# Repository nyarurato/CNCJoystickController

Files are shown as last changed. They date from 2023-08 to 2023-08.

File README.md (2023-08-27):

# CNCJoystickController
CNC Joystick Controller for RepRap Firmware Duet3

Using in 
https://bbs.avalontech.jp/t/topic/1473

# DEMO

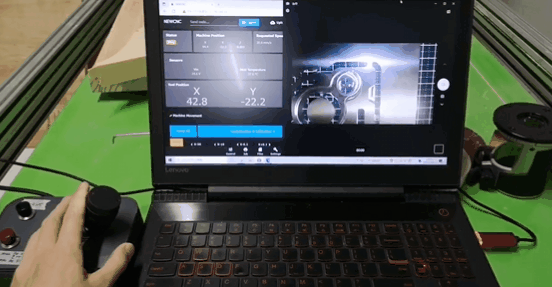
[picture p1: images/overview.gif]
demo


from: https://twitter.com/Gymnopedian/status/1694639996589015279

# Licence
## Hardware
[CC BY-SA 4.0](https://creativecommons.org/licenses/by-sa/4.0/)

## Software
[GPLv3](https://www.gnu.org/licenses/gpl-3.0.html)

Software is forked from https://github.com/Duet3D/CNC-Pendant-Firmware

# Author
[nyaruarto](https://github.com/nyarurato)

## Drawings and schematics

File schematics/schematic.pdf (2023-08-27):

# GND 2 5

JP1123

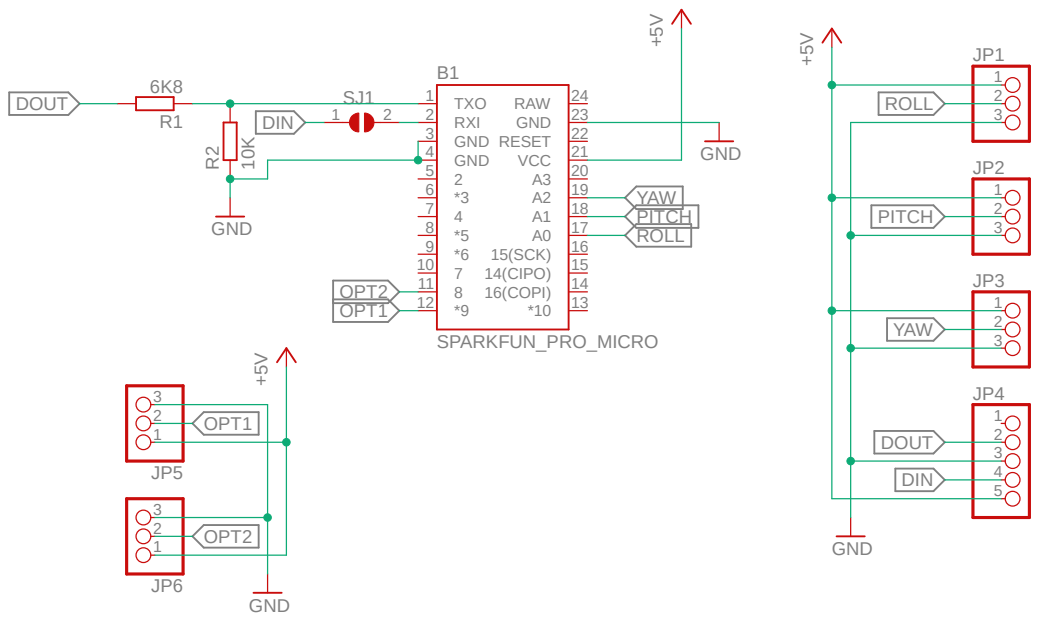
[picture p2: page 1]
SPARKFUN_PRO_MICRO ⁺⁵V; GND; GND +5V; 13 16(COPI); 14 14(CIPO); 15 15(SCK); 20 GND 4; 23 RAW; GND 3; RESET; 22 RXI 2; TXO 1; VCC; ROLL; PITCH; YAW; DOUT; DIN; OPT1; OPT2

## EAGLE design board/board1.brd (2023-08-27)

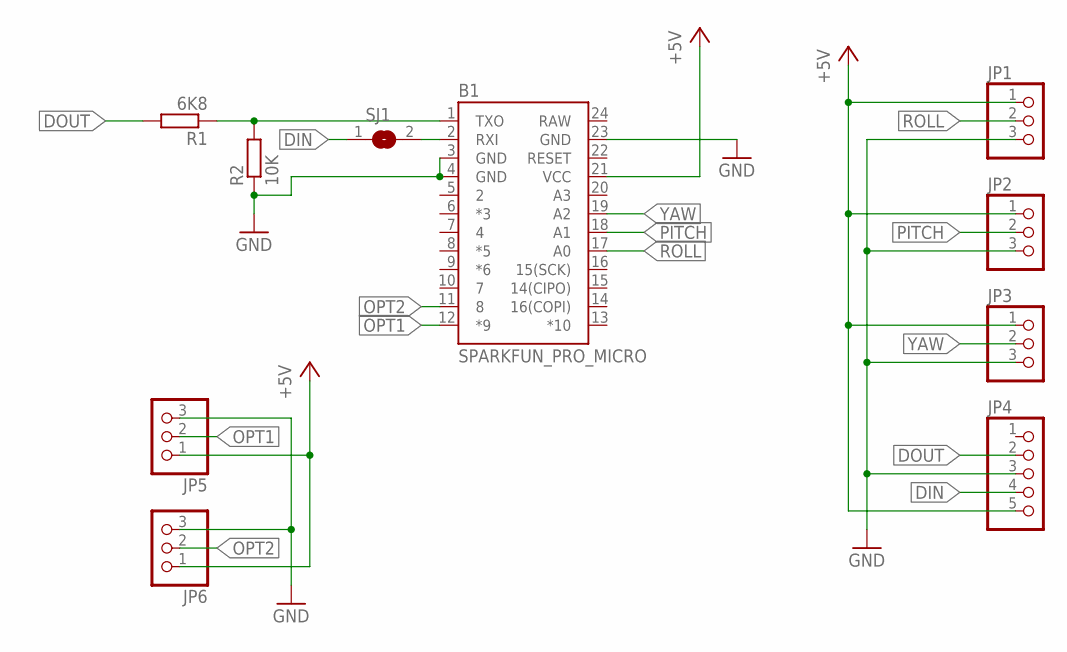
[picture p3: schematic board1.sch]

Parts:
B1: SPARKFUN_PRO_MICRO
JP1, JP2, JP3, JP5, JP6: PINHD-1X3; 1X03
JP4: PINHD-1X5; 1X05
R1: 6K8; R0603
R2: 10K; R0603
SJ1: SJ

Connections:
+5V: B1.21 (VCC), JP1.1, JP2.1, JP3.1, JP4.5, JP5.1, JP6.1
DIN: JP4.4, SJ1.1
DOUT: JP4.2, R1.2
GND: B1.3 (GND), B1.4 (GND), B1.23 (GND), JP1.3, JP2.3, JP3.3, JP4.3, JP5.3, JP6.3, R2.1
unnamed: B1.1 (TXO), R1.1, R2.2
unnamed: B1.2 (RXI), SJ1.2
OPT1: B1.12 (*9), JP5.2
OPT2: B1.11 (8), JP6.2
PITCH: B1.18 (A1), JP2.2
RAW: B1.24 (RAW)
ROLL: B1.17 (A0), JP1.2
YAW: B1.19 (A2), JP3.2

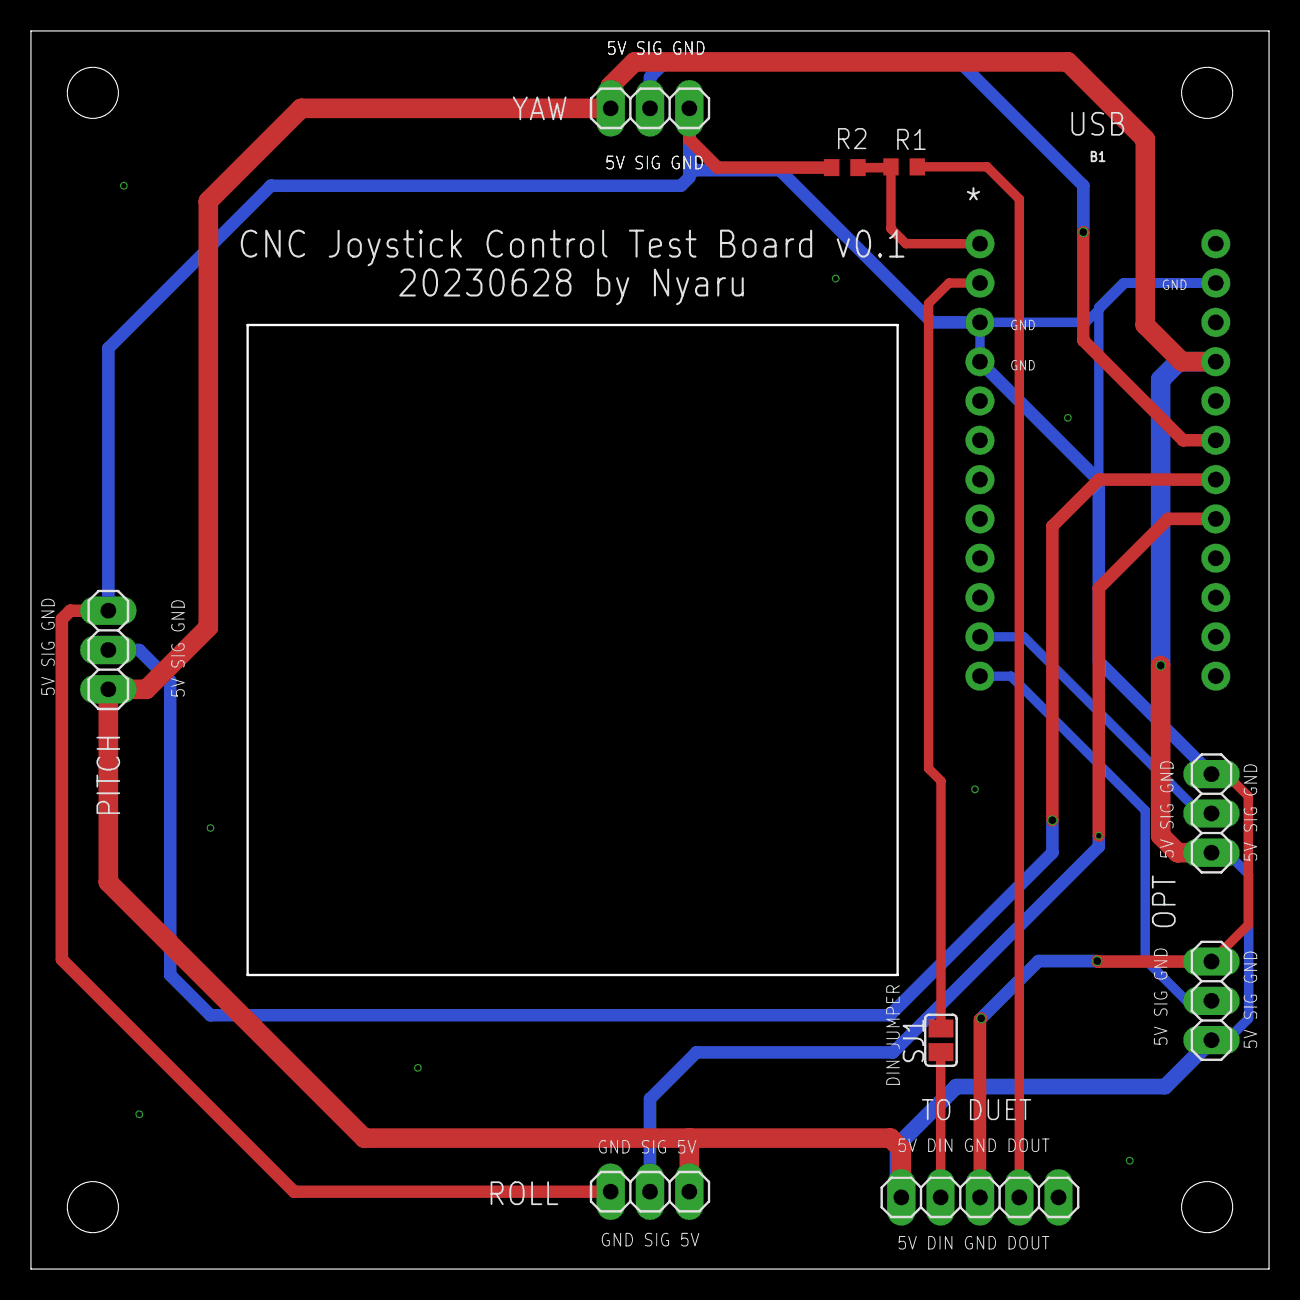
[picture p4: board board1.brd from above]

Board: 2 copper layers, 80.0 x 80.0 mm, 10 parts (0 on the bottom side), 11 nets.

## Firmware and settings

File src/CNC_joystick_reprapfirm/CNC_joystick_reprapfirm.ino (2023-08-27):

// CNC pendant interface to Duet
// Configuration constants
const int PinP = A1;
const int PinR = A0;
const int PinY = A2;

const int PinOP1 = 9;
const int PinOP2 = 8;

const unsigned long BaudRate = 57600;
const unsigned long MinCommandInterval = 20;

// Table of commands we send, one entry for each axis
const char* MoveCommands = "G91 G0 ";

#include "GCodeSerial.h"
#include "PassThrough.h"
PassThrough passThrough;

#include <avdweb_Switch.h>
Switch button_op1 = Switch(PinOP1);
Switch button_op2 = Switch(PinOP2);

const char* const ToggleOutCommands[] = {"M42 P0 S0.0\n","M42 P0 S1.0\n"};

bool toggle_out = false;

int serialBufferSize;
int distanceMultiplier;
int axis;
uint32_t whenLastCommandSent = 0;

const int axisPins[] = { PinR, PinP, PinY};

int pre_p = 0;
int pre_r = 0;
int pre_y = 0;

int mid = 512;

int c_p = 0;
int c_r = 0;
int c_y = 0;

bool go_axis[3] = {false,false,false}; 
int distance[3] = {0,0,0};

const char* const axisName[] = {" X"," Y"," Z"};

#define UartSerial   Serial1

GCodeSerial output(UartSerial);

const int div_input = 200;
const int div_move = 1000;

void setup()
{
  output.begin(BaudRate);

  //Serial.begin(BaudRate);//debug

  serialBufferSize = output.availableForWrite();

#if defined(__AVR_ATmega32U4__)     // Arduino Leonardo or Pro Micro
  TX_RX_LED_INIT;
#endif
}

// Check for received data from PanelDue, store it in the pass through buffer, and send it if we have a complete command
void checkPassThrough()
{
  unsigned int commandLength = passThrough.Check(UartSerial);
  if (commandLength != 0 && UartSerial.availableForWrite() == serialBufferSize)
  {
    output.write(passThrough.GetCommand(), commandLength);
  }
}

int tmp = 0;
void loop()
{

  c_r = analogRead( PinR );
  c_p = analogRead( PinP );
  c_y = analogRead( PinY );        

  tmp = ((c_r - mid)/div_input);
  if(abs(tmp)>=1){
    distance[0] = tmp;
  }else{
    distance[0] = 0;
  }

  tmp = ((c_p - mid)/div_input);
  if(abs(tmp)>=1){
    distance[1] = tmp;
  }else{
    distance[1] = 0;
  }

  tmp = ((c_y - mid)/div_input);
  if(abs(tmp)>=1){
    distance[2] = tmp;
  }else{
    distance[2] = 0;
  }
  
  // If the serial output buffer is empty, send a G0 command for the accumulated encoder motion.
  if (output.availableForWrite() == serialBufferSize)
  {
#if defined(__AVR_ATmega32U4__)     // Arduino Micro, Pro Micro or Leonardo
    TXLED1;                         // turn off transmit LED
#endif
    const uint32_t now = millis();
    if (now - whenLastCommandSent >= MinCommandInterval)
    {

#if defined(__AVR_ATmega32U4__)     // Arduino Micro, Pro Micro or Leonardo
        TXLED0;                     // turn on transmit LED
#endif
        button_op1.poll();
        button_op2.poll();
        whenLastCommandSent = now;

        if(button_op1.pushed()){
          output.write("G28\n");
        }

        if(button_op2.pushed()){
          toggle_out = !toggle_out;
          output.write(ToggleOutCommands[(int)toggle_out]);
          //Serial.println(ToggleOutCommands[(int)toggle_out]);
        }

        if((distance[0] != 0)||(distance[1] != 0)||(distance[2] != 0)){
          output.write(MoveCommands);

          for(int i=0;i<3;i++){
          
            if(distance[i] != 0){
              output.write(axisName[i]);
              if (distance[i] < 0)
              {
                output.write('-');
                distance[i] = -distance[i];
              }
              output.print(distance[i]/div_move);
              output.write('.');
              output.print(distance[i] % div_move);
              
            }
          }
          output.write('\n');
        }
        
        
    }
  }

  checkPassThrough();
}

// End

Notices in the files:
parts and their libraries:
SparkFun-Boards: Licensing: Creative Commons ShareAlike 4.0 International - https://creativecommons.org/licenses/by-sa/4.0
